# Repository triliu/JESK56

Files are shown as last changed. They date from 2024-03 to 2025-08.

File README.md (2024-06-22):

# JESK56

The JESK56 is a diodeless 56-key ortholinear keyboard, using a single QMK-compatible RP2040-based microcontroller. The JESK56 utilises a new type of circuit design stemming from graph theory and mathematical design theory. All previous diodeless keyboards on the market have at most 21 keys per microcontroller. So all such keyboards must be split into two halves to function as a regular keyboard, and must use two microcontrollers over the two halves. This makes the JESK56 the first non-split diodeless keyboard. 

Due to its diodeless-ness, the JESK56 is ideal for the custom keyboard community, as it reduces the cost and complexity of making a custom mechanical keyboard.




## Why 'JESK'?

Typical mechanical keyboards arrange their keys in a grid pattern. In such a grid, there are cycles of four keys. If no diodes were used and three keys of a four-key cycle were pressed, the keyboard would act like all four keys were being pressed. See https://pcbheaven.com/wikipages/How_Key_Matrices_Works/ for an explainer of this phenomenon. By adding a diode to every key, the keyboard becomes "n-key-rollover", meaning that the keyboard can theoretically distinguish all combinations of keypresses. In software, however, 6-key rollover is typically used, meaning the software assumes that if more than six keys are being pressed, then keys were pressed on accident. Common standards are 2-key-rollover (such as in membrane keybards), 6-key-rollover (mechanical/gaming keyboards), and n-key-rollover (where all combinations of keypresses are distinguished). These are often written as 2KRO, 6KRO, and NKRO. The JESK56 obtains 4-key-rollover, although the board has been specifically designed to function as a n-key-rollover in almost all practical situations. 

In graph theory, it is possible to make graphs that do not contain small cycles. Each graph can be converted into a new type of key matrix, with differing characteristics. A recent paper studied graphs of high algebraic connectivity; see [Attainable bounds for algebraic connectivity and maximally-connected regular graphs](https://arxiv.org/abs/2307.07308). They found a graph of girth 6 (no 3-, 4-, or 5-cycles) with 28 vertices and 56 edges. JESK is an acronym of the four authors' surnames: Janssen, Exoo, Salamon, and Kolokolnikov. 



For more details on this graph, see [House of Graphs](https://houseofgraphs.org/graphs/49998). This converts to a key matrix with just a 4-key rollover (4KRO). However, by designing the board specifically, all problematic 5-key and 6-key sequences may be practically eliminated. When each finger uses one column (or half a row for the thumb keys), the JESK56 will have NKRO as long as you do not press two pairs of keys (4 keys) with each pair of keysactivated using the same finger (i.e. in the same coloumn/thumb row).

This design is powered using an RP2040-powered microcontroller with 28 pins. I suggest the 16M version of the following: See https://www.aliexpress.com/item/1005006130019224.html
## What files are here
- Gerber files for production
- QMK firmware
- 3D files for the case

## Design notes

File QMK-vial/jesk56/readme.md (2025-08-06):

# Jesk56

triliu - Jesk56

Explainer

* Keyboard Maintainer: [Triliu](https://github.com/triliu) 
* Hardware Supported: Jesk56 v1
* Hardware Availability: (coming)

Place these files in .../qmk_firmware/keyboards/triliu/jesk56

To compile in QMK MYSY, run command:

    qmk compile -kb triliu/jesk56/rp2040 -km default

Make example for this keyboard (after setting up your build environment):

    make triliu/jesk56/rp2040:default

Flashing example for this keyboard:

    make triliu/jesk56/rp2040:default:flash

First time accessing the bootloader, you might have to hold the boot button and then press the reset button. 
Subsequently, enter bootloader by double-tapping reset button

See the [build environment setup](https://docs.qmk.fm/#/getting_started_build_tools) and the [make instructions](https://docs.qmk.fm/#/getting_started_make_guide) for more information. Brand new to QMK? Start with our [Complete Newbs Guide](https://docs.qmk.fm/#/newbs).

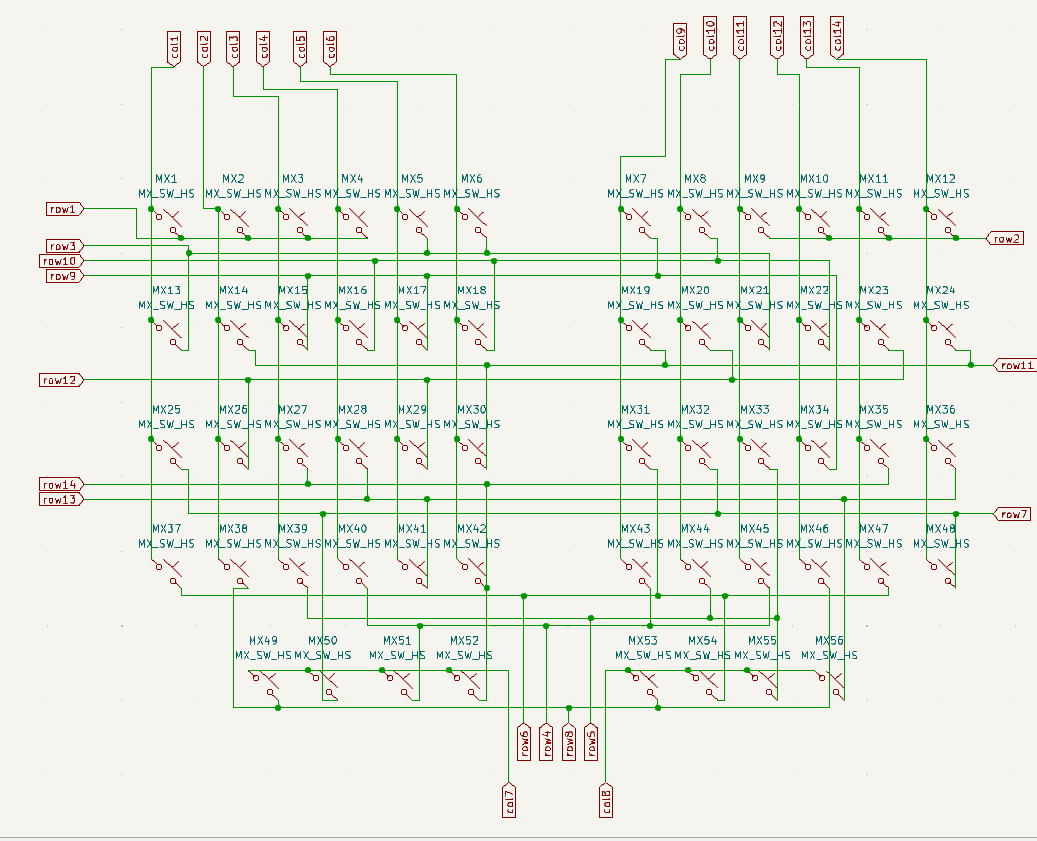
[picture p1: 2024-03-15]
KiCad/JESK56_schematic_switches.png

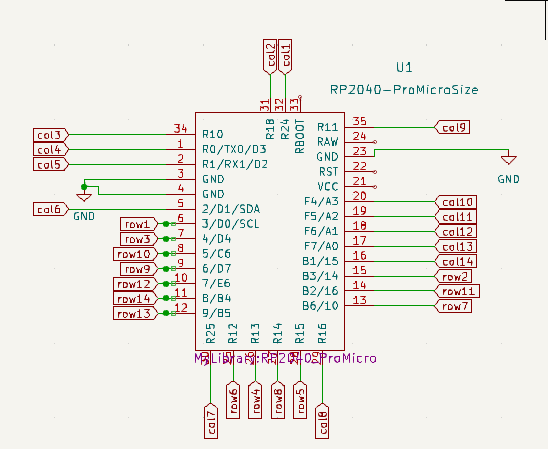
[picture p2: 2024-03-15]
KiCad/JESK56_schematic_IC.png

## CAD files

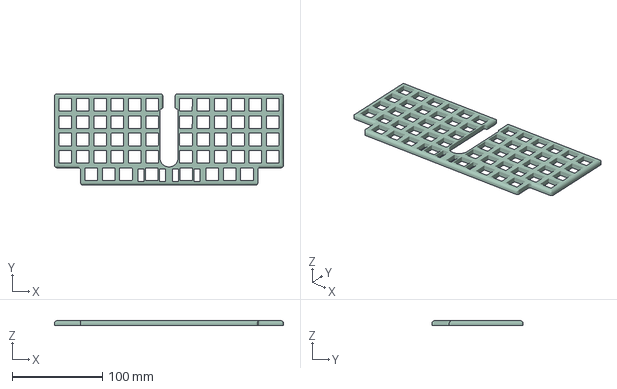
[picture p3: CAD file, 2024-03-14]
3d_print_files/JESK56_top_plate v2.3mf
254.0 x 101.3 x 5.20 mm

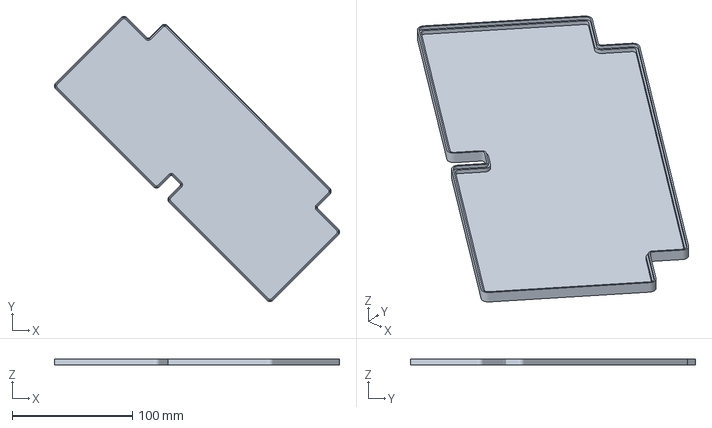
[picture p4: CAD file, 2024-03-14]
3d_print_files/JESK56_bottom_plates v2.3mf
237.5 x 237.5 x 5.20 mm

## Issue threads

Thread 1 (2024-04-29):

Erroneous statement in readme

gsuberland, 2024-04-29:
Hi! I stumbled across this from a Mastodon post, and noticed you'd said "The USB keyboard protocol is limited to a 6-key rollover" in the readme. This isn't actually true; it's a popular misconception.

The basic USB keyboard interface used by BIOS/UEFI is limited to 6KRO, but as soon as you include a proper USB HID descriptor you can do NKRO just fine. See https://www.devever.net/~hl/usbnkro for info.

Might wanna correct that in the readme :)

Cool concept though. I've done some fun stuff with diodeless multi-key detection by switching between I/O modes on GPIOs, which I've nicknamed "jimmyplexing", but the graph theory side of it is new to me and a really cool way to formalise it.

triliu, 2024-06-22:
Thank you for this correction! I was trying to be as simple as possible with this comment about 6KRO, although I see I have stepped out of accuracy. I have deleted this line, and added some further comments about the key-rollover of the board.

It has taken a little while to address this, sorry. The issue is with trying to quickly emphasise that 6KRO is a common and decent standard, while also trying to keep the introduction as non-technical as possible (while also adding in accuracy for the mathematics). One part of this keyboard I am trying to emphasise is that it will make a great first custom keyboard for newcomers who want to build their own board. (Another is that this is leading into a mathematics research project).

It is a bit hard to navigate all the technologies in terms of which technologies support going beyond 6KRO. I believe both QMK and ZMK use 6KRO as a base, although this can be bumped up to NKRO pretty easily (although I have heard some people have issues with getting NKRO to actually work). A bunch of decent keyboards only support 6KRO. Many keyboards only support 2KRO. All we really need to say is that 6KRO is a good standard, from which we can argue that the key rollover effects of the JESK56 is actually comparable to this standard - It only has 4KRO, but in practise it is almost NKRO.

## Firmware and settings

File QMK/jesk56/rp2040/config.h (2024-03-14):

// Copyright 2024 Trent G. Marbach (https://github.com/triliu)
// SPDX-License-Identifier: GPL-2.0-or-later
#pragma once
#define RP2040_BOOTLOADER_DOUBLE_TAP_RESET
#define RP2040_BOOTLOADER_DOUBLE_TAP_RESET_TIMEOUT 200U
#define SERIAL_USART_FULL_DUPLEX
#define SERIAL_USART_TX_PIN GP0
#define SERIAL_USART_RX_PIN GP1
#define I2C_DRIVER I2CD1
#define I2C1_SDA_PIN GP22
#define I2C1_SCL_PIN GP23

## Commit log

2024-03-14 Added all files
    [JESK56_bottom_plates v2.3mf, JESK56_top_plate v2.3mf]
2024-03-15 added schematic
